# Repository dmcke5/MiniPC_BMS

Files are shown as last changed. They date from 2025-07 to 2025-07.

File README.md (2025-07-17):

# MiniPC BMS
A tiny UPS for powering Mini PC's from battery!

 PMS

## Features:
- USB-C PD charging
- Secondary charger input
- USB-HID UPS communication to provide the operating system with battery information
- Inbuilt fuel gauge IC for accurate battery capacity monitoring
- Extremely low powered-down power consumption (5.1uA)
- Inbuilt 19v boost for stable output at up to 3A.
- Solid state switch for triggering PC power button

## Software:
The software for this project is based on this HID power device library:
https://github.com/abratchik/HIDPowerDevice

The software is complete and functional, although it could use some polish and some comments.
I would recommend changing the "debug" variable in MiniPC_UPS.ino to true before you flash the code for the first time.
This will enable debug output and stop the BMS from trying to shut your computer down due to a "Low battery".
Once you've confirmed all of the values are being read correctly, you should be safe to go back in and set that variable to false
and the BMS will begin functioning.

## Known issues

USB-C PD charging is slow. I found a small issue in the PCB design (which I have now fixed) before uploading that may or may not have solved this problem. I suspect that the issues I've had with this are just down to soldering or faulty hardware because the second charger input works as intended and it is basically identical to the first one after all of the USB PD components. I have checked and the correct values are being requested from the USB charger so the issue has somewhere down the line from the USB PD hardware. This was working for me at one stage, which is why I suspect its an assembly issue.

USB HID is sometimes not detected by windows. This one has been difficult to track down, but I'm certain its a software issue that's causing the problem. A simple restart of the system always seems to rectify the problem so I've left it alone for now.

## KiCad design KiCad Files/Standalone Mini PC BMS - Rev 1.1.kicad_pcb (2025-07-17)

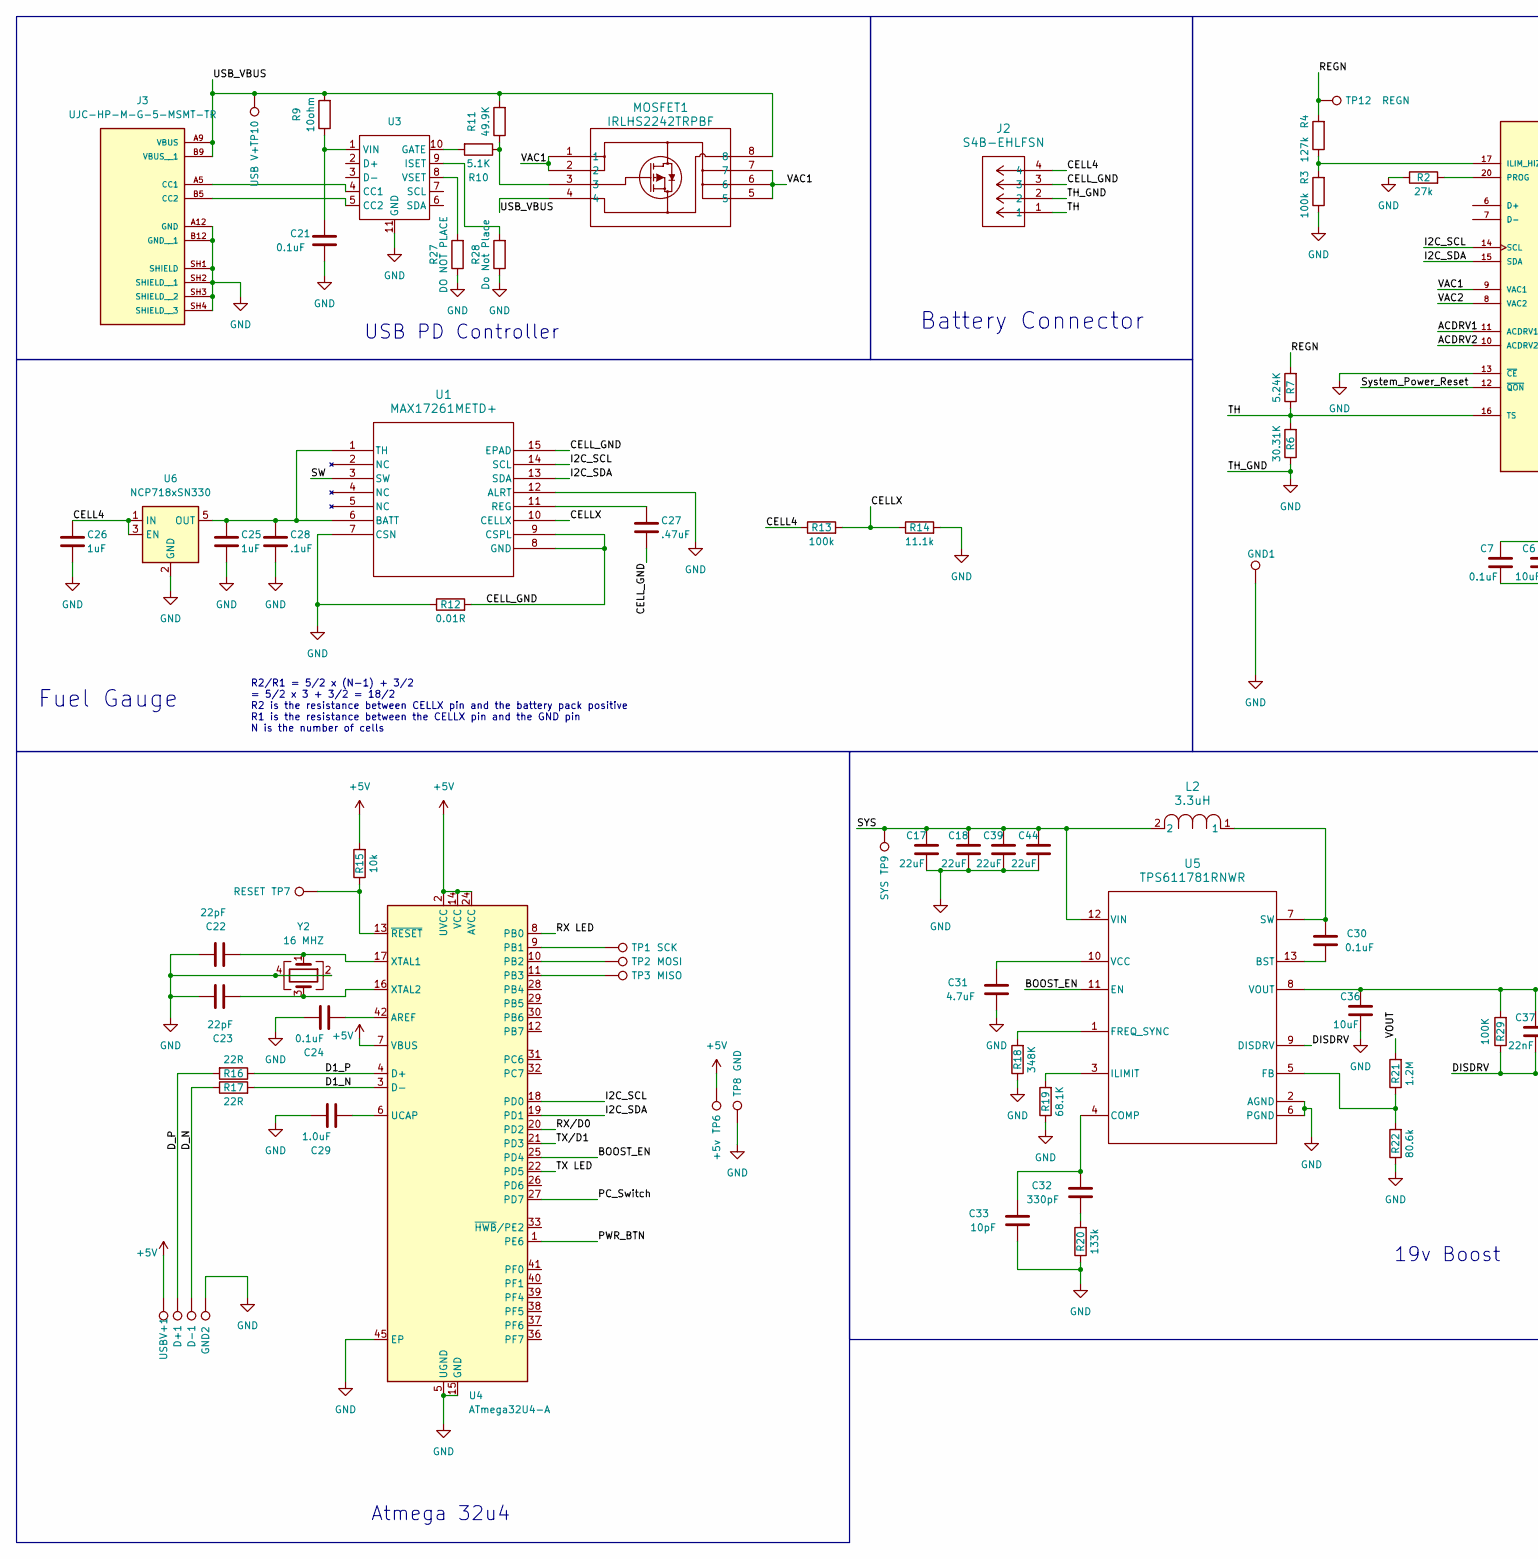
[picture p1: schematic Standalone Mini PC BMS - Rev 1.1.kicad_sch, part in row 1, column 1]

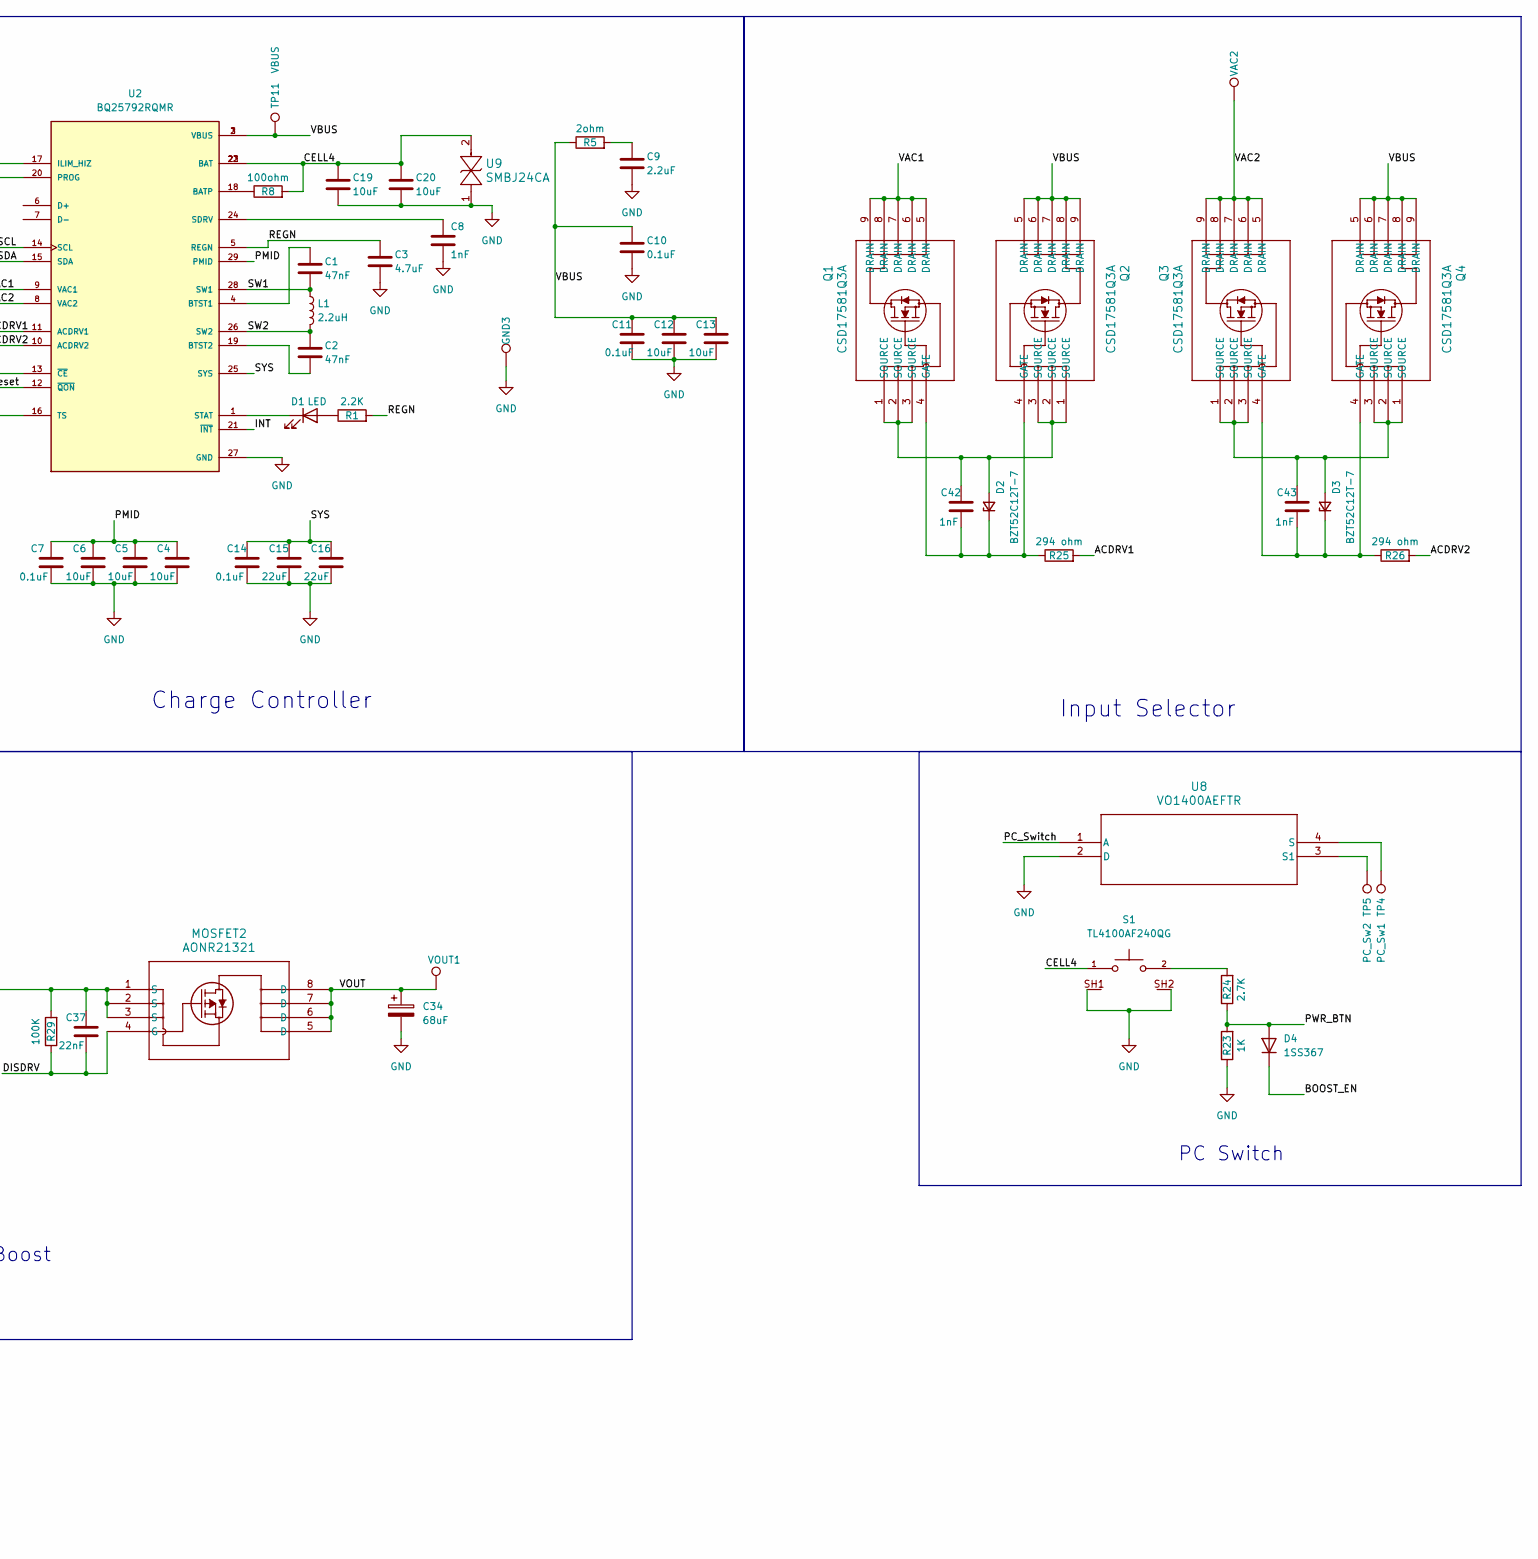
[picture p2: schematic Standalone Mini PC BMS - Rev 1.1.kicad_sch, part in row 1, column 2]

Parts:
C1, C2: 47nF; C_0603_1608Metric
C3, C31: 4.7uF; C_0603_1608Metric
C4, C5, C6, C12, C13, C36: 10uF; C_0805_2012Metric
C7, C10, C11, C14, C24, C30: 0.1uF; C_0603_1608Metric
C8, C42, C43: 1nF; C_0603_1608Metric
C9: 2.2uF; C_0603_1608Metric
C15, C16, C17, C18, C39, C44: 22uF; C_0805_2012Metric
C19, C20: 10uF; C_0603_1608Metric
C21: 0.1uF; C_0603_1608Metric_Pad1.08x0.95mm_HandSolder
C22, C23: 22pF; C_0603_1608Metric
C25, C26: 1uF; C_0603_1608Metric
C27: .47uF; C_0603_1608Metric
C28: .1uF; C_0603_1608Metric
C29: 1.0uF; C_0603_1608Metric
C32: 330pF; C_0603_1608Metric
C33: 10pF; C_0603_1608Metric
C34: 68uF; CP_Radial_D5.0mm_P2.00mm
C37: 22nF; C_0603_1608Metric
D1: LED; LED_0603_1608Metric
D2, D3: BZT52C12T-7; SOD-523_0P9X1P3_ONS
D4: 1SS367; D_SOD-323
D+1: D+; TestPoint_THTPad_D1.5mm_Drill0.7mm
D-1: D-; TestPoint_THTPad_D1.5mm_Drill0.7mm
GND1: GND; TestPoint_THTPad_D2.0mm_Drill1.0mm
GND2, GND3: GND; TestPoint_THTPad_D1.5mm_Drill0.7mm
J2: S4B-EHLFSN; CONN_S4B-EHLFSN_JST
J3: UJC-HP-M-G-5-MSMT-TR; CUI_UJC-HP-M-G-5-MSMT-TR; PARTREV 1.01
L1: 2.2uH; IND_SPM6530_TDK
L2: 3.3uH; IND_1050-WE-HCI_WRE
MOSFET1: IRLHS2242TRPBF; PQFN6_2X2_INF
MOSFET2: AONR21321; DFN8_3x3_EP_AOS
Q1, Q2, Q3, Q4: CSD17581Q3A; Q3A_TEX
R1: 2.2K; R_0603_1608Metric
R2: 27k; R_0603_1608Metric
R3, R13: 100k; R_0603_1608Metric
R4: 127k; R_0603_1608Metric
R5: 2ohm; R_0603_1608Metric
R6: 30.31K; R_0603_1608Metric
R7: 5.24K; R_0603_1608Metric
R8: 100ohm; R_0603_1608Metric
R9: 10ohm; R_0603_1608Metric_Pad0.98x0.95mm_HandSolder
R10: 5.1K; R_0603_1608Metric_Pad0.98x0.95mm_HandSolder
R11: 49.9K; R_0603_1608Metric_Pad0.98x0.95mm_HandSolder
R12: 0.01R; R_2512_6332Metric
R14: 11.1k; R_0603_1608Metric
R15: 10k; R_0603_1608Metric
R16, R17: 22R; R_0603_1608Metric
R18: 348K; R_0603_1608Metric
R19: 68.1K; R_0603_1608Metric
R20: 133k; R_0603_1608Metric
R21: 1.2M; R_0603_1608Metric
R22: 80.6k; R_0603_1608Metric
R23: 1K; R_0603_1608Metric
R24: 2.7K; R_0603_1608Metric
R25, R26: 294 ohm; R_0603_1608Metric
R27: DO NOT PLACE; R_0603_1608Metric_Pad0.98x0.95mm_HandSolder
R28: Do Not Place; R_0603_1608Metric_Pad0.98x0.95mm_HandSolder
R29: 100K; R_0603_1608Metric
S1: TL4100AF240QG; SW_TL4100AF240QG; PARTREV C
TP1: SCK; TestPoint_Pad_D1.0mm
TP2: MOSI; TestPoint_Pad_D1.0mm
TP3: MISO; TestPoint_Pad_D1.0mm
TP4: PC_Sw1; TestPoint_THTPad_D1.5mm_Drill0.7mm
TP5: PC_Sw2; TestPoint_THTPad_D1.5mm_Drill0.7mm
TP6: +5v; TestPoint_Pad_D1.0mm
TP7: RESET; TestPoint_Pad_D1.0mm
TP8: GND; TestPoint_Pad_D1.0mm
TP9: SYS; TestPoint_Pad_D1.0mm
TP10: USB V+; TestPoint_Pad_D1.0mm
TP11: VBUS; TestPoint_Pad_D1.0mm
TP12: REGN; TestPoint_Pad_D1.0mm
U1: MAX17261METD+; 21-0137_T1433+2C_MXM
U2: BQ25792RQMR; QFN40P400X400X100-29N; PARTREV 11/2019
U3: DFN-10-1EP_3x3mm_P0.5mm_EP1.7x2.5mm
U4: ATmega32U4-A; QFN-44-1EP_7x7mm_P0.5mm_EP5.15x5.15mm
U5: TPS611781RNWR; RNW0013A
U6: NCP718xSN330; SOT-23-5
U8: VO1400AEFTR; SO-4_VO_VIS
U9: SMBJ24CA; SMBJ24CA_LTF
USBV+1: USB V+; TestPoint_THTPad_D1.5mm_Drill0.7mm
VAC2: VAC2; TestPoint_THTPad_D1.5mm_Drill0.7mm
VOUT1: V+ OUT; TestPoint_THTPad_D2.0mm_Drill1.0mm
Y2: 16 MHZ; Crystal_SMD_5032-4Pin_5.0x3.2mm

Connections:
+5V: R15.2, TP6.1, U4.2 (UVCC), U4.7 (VBUS), U4.14 (VCC), U4.24 (AVCC), U4.34 (VCC), U4.44 (AVCC), USBV+1.1
/ACDRV1: R25.2, U2.11 (ACDRV1)
/ACDRV2: R26.2, U2.10 (ACDRV2)
/BOOST_EN: D4.1 (K), U4.25 (PD4), U5.11 (EN)
/CELL4: C19.1, C20.1, C26.1, J2.4, R8.2, R13.1, S1.1, U2.22 (BAT), U2.23 (BAT), U6.1 (IN), U6.3 (EN), U9.2
/CELLX: R13.2, R14.1, U1.10 (CELLX)
/CELL_GND: C27.2, J2.3, R12.2, U1.8 (GND), U1.9 (CSPL), U1.15 (EPAD)
/D1_N: R17.2, U4.3 (D-)
/D1_P: R16.1, U4.4 (D+)
/DISDRV: C37.2, MOSFET2.4 (G), R29.1, U5.9 (DISDRV)
/D_N: D-1.1, R17.1
/D_P: D+1.1, R16.2
/I2C_SCL: U1.14 (SCL), U2.14 (SCL), U4.18 (PD0)
/I2C_SDA: U1.13 (SDA), U2.15 (SDA), U4.19 (PD1)
/INT: U2.21 (~INT)
/PC_Switch: U4.27 (PD7), U8.1 (A)
/PMID: C4.1, C5.1, C6.1, C7.1, U2.29 (PMID)
/PWR_BTN: D4.2 (A), R23.2, R24.1, U4.1 (PE6)
/REGN: C3.1, R1.2, R4.2, R7.2, TP12.1, U2.5 (REGN)
/RX LED: U4.8 (PB0)
/RX/D0: U4.20 (PD2)
/SW: U1.3 (SW)
/SW1: C1.2, L1.1, U2.28 (SW1)
/SW2: C2.1, L1.2, U2.26 (SW2)
/SYS: C14.1, C15.1, C16.1, C17.1, C18.1, C39.1, C44.1, L2.2, TP9.1, U2.25 (SYS), U5.12 (VIN)
/System_Power_Reset: U2.12 (~QON)
/TH: J2.1, R6.2, R7.1, U2.16 (TS)
/TX LED: U4.22 (PD5)
/TX/D1: U4.21 (PD3)
/USB_VBUS: J3.A9 (VBUS), J3.B9 (VBUS__1), MOSFET1.4, MOSFET1.8, R9.2, R11.2, TP10.1
/VAC1: MOSFET1.1, MOSFET1.2, MOSFET1.5, MOSFET1.6, MOSFET1.7, Q1.5 (DRAIN), Q1.6 (DRAIN), Q1.7 (DRAIN), Q1.8 (DRAIN), Q1.9 (DRAIN), U2.9 (VAC1)
/VAC2: Q3.5 (DRAIN), Q3.6 (DRAIN), Q3.7 (DRAIN), Q3.8 (DRAIN), Q3.9 (DRAIN), U2.8 (VAC2), VAC2.1
/VBUS: C10.1, C11.1, C12.1, C13.1, Q2.5 (DRAIN), Q2.6 (DRAIN), Q2.7 (DRAIN), Q2.8 (DRAIN), Q2.9 (DRAIN), Q4.5 (DRAIN), Q4.6 (DRAIN), Q4.7 (DRAIN), Q4.8 (DRAIN), Q4.9 (DRAIN), R5.1, TP11.1, U2.2 (VBUS), U2.3 (VBUS)
/VOUT: C34.1, MOSFET2.5 (D), MOSFET2.6 (D), MOSFET2.7 (D), MOSFET2.8 (D), R21.2, VOUT1.1
GND: C3.2, C4.2, C5.2, C6.2, C7.2, C8.2, C9.2, C10.2, C11.2, C12.2, C13.2, C14.2, C15.2, C16.2, C17.2, C18.2, C19.2, C20.2, C21.2, C22.1, C23.1, C24.1, C25.2, C26.2, C28.2, C29.1, C31.1, C33.1, C34.2, C36.2, C39.2, C44.2, GND1.1, GND2.1, GND3.1, J2.2, J3.A12 (GND), J3.B12 (GND__1), J3.SH1 (SHIELD), J3.SH2 (SHIELD__1), J3.SH3 (SHIELD__2), J3.SH4 (SHIELD__3), R2.1, R3.1, R6.1, R12.1, R14.2, R18.1, R19.1, R20.1, R22.1, R23.1, R27.1, R28.1, S1.SH1, S1.SH2, TP8.1, U1.7 (CSN), U1.12 (ALRT), U2.13 (~CE), U2.27 (GND), U3.11 (GND), U4.5 (UGND), U4.15 (GND), U4.23 (GND), U4.35 (GND), U4.43 (GND), U4.45 (EP), U5.2 (AGND), U5.6 (PGND), U6.2 (GND), U8.2 (D), U9.1, Y2.2, Y2.4
unnamed: C9.1, R5.2
unnamed: C32.1, R20.2
unnamed: D1.2 (A), R1.1
unnamed: D1.1 (K), U2.1 (STAT)
unnamed: C42.1, D2.2 (A), Q1.1 (SOURCE), Q1.2 (SOURCE), Q1.3 (SOURCE), Q2.1 (SOURCE), Q2.2 (SOURCE), Q2.3 (SOURCE)
unnamed: C42.2, D2.1 (K), Q1.4 (GATE), Q2.4 (GATE), R25.1
unnamed: C43.1, D3.2 (A), Q3.1 (SOURCE), Q3.2 (SOURCE), Q3.3 (SOURCE), Q4.1 (SOURCE), Q4.2 (SOURCE), Q4.3 (SOURCE)
unnamed: C43.2, D3.1 (K), Q3.4 (GATE), Q4.4 (GATE), R26.1
unnamed: J3.A5 (CC1), U3.4 (CC1)
unnamed: J3.B5 (CC2), U3.5 (CC2)
unnamed: MOSFET1.3, R10.1, R11.1
unnamed: R24.2, S1.2
unnamed: C25.1, C28.1, U1.1 (TH), U1.6 (BATT), U6.5 (OUT)
unnamed: C27.1, U1.11 (REG)
unnamed: R8.1, U2.18 (BATP)
unnamed: C1.1, U2.4 (BTST1)
unnamed: C2.2, U2.19 (BTST2)
unnamed: R3.2, R4.1, U2.17 (ILIM_HIZ)
unnamed: R2.2, U2.20 (PROG)
unnamed: C8.1, U2.24 (SDRV)
unnamed: R10.2, U3.10 (GATE)
unnamed: R28.2, U3.9 (ISET)
unnamed: C21.1, R9.1, U3.1 (VIN)
unnamed: R27.2, U3.8 (VSET)
unnamed: C24.2, U4.42 (AREF)
unnamed: TP1.1, U4.9 (PB1)
unnamed: TP2.1, U4.10 (PB2)
unnamed: TP3.1, U4.11 (PB3)
unnamed: C29.2, U4.6 (UCAP)
unnamed: C22.2, U4.17 (XTAL1), Y2.1
unnamed: C23.2, U4.16 (XTAL2), Y2.3
unnamed: R15.1, TP7.1, U4.13 (~RESET)
unnamed: C30.1, U5.13 (BST)
unnamed: C32.2, C33.2, U5.4 (COMP)
unnamed: R21.1, R22.2, U5.5 (FB)
unnamed: R18.2, U5.1 (FREQ_SYNC)
unnamed: R19.2, U5.3 (ILIMIT)
unnamed: C30.2, L2.1, U5.7 (SW)
unnamed: C31.2, U5.10 (VCC)
unnamed: C36.1, C37.1, MOSFET2.1 (S), MOSFET2.2 (S), MOSFET2.3 (S), R29.2, U5.8 (VOUT)
unnamed: TP5.1, U8.3 (S1)
unnamed: TP4.1, U8.4 (S)

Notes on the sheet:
USB PD Controller
19v Boost
Atmega 32u4
PC Switch
Input Selector
Fuel Gauge
R2/R1 = 5/2 x (N-1) + 3/2 = 5/2 x 3 + 3/2 = 18/2 R2 is the resistance between CELLX pin and the battery pack positive R1 is the resistance between the CELLX pin and the GND pin N is the number of cells
Battery Connector
Charge Controller

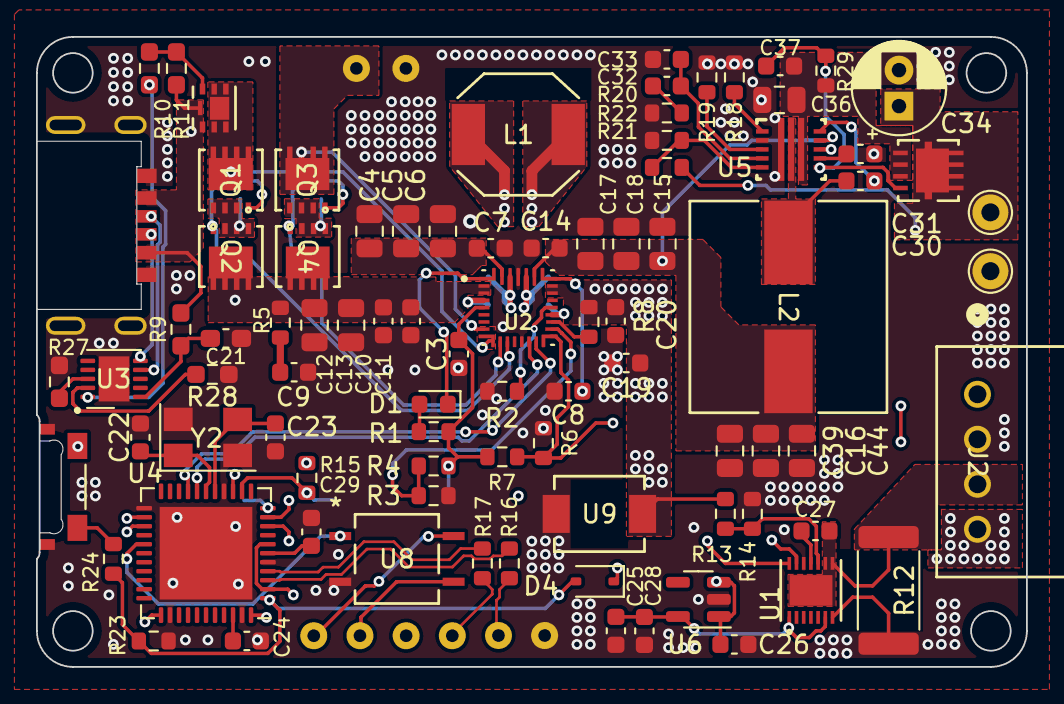
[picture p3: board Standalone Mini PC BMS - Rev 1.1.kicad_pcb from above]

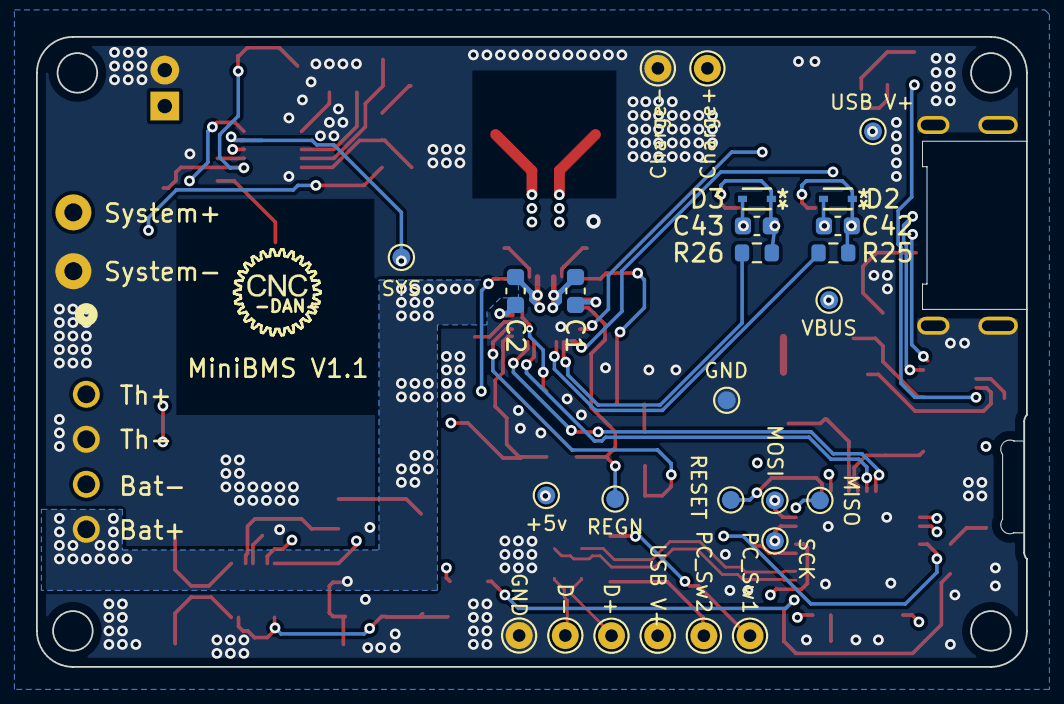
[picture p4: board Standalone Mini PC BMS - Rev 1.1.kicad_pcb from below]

Board: 4 copper layers, 55.0 x 35.0 mm, 113 parts (26 on the bottom side), 70 nets.

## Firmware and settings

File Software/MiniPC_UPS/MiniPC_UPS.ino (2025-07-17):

#include <Wire.h>
#include <HIDPowerDevice.h>
//#include <LowPower.h>

//User Config
#define powerOffDelay 10000 //Time in milliseconds to hold power button for hard shut off
#define shutdownDelay 2000  //Time in milliseconds to hold power button to initiate Shutdown
#define reportDelay 5000    //Time in milliseconds. How often to Update UPS info
int batteryCapacity = 5000; //Battery Design Capacity in mAh
bool disableAutoShutoff = false; //Used to disable power sense shutdown for testing
bool debug = false;         //Set to True to disable UPS functionality and enable serial logging.
bool forceFuelGaugeReset = false; //Set to True to reset fuel gauge on startup. Learnt battery information will be lost!

//Pin configuration
int boostEnable = 4; //PD4 // Enables 19v Boost Output
int pcSwitch = 6; //PD7  // High to trigger PC power button press
//int pcPower = 12; //PD6 // Input to sense if PC is powered on
int pwrButton = 7; //PE6 // Power button

//bool systemAwake = true;
int StatusPOR = 0; //This Variable is set to 1 by the Fuel gauge on first power up
bool updateBQ = false;

//Timers
unsigned long shutdownTimer = 0;
unsigned long powerBtnTimer = 0;
unsigned long reportTimer = 0;

//UPS
int batterySOC;
bool bCharging = false;
bool bACPresent = false;
bool bDischarging = false;
byte iRemaining =0, iPrevRemaining=0;
bool lastACState = false;
bool lastChargeState = false;

int powerSupplyState = 0; //0 = Active, 1 = Sleep, 2 = Powered Down

void setup() {
  TXLED0;
  RXLED0;
  if(debug){
    Serial.begin(57600);
    while(!Serial){}
  }
  Wire.begin();

  max17261Init(); //Set up fuel gauge

  //Configure IO pins
  pinMode(boostEnable, OUTPUT);
  pinMode(pcSwitch, OUTPUT);
  //pinMode(pcPower, INPUT);
  pinMode(pwrButton, INPUT);

  //Enable Boost 
  digitalWrite(boostEnable, HIGH);

  //Setup UPS
  if(!debug){
    UPS_Setup();
  }

  //Setup BQ25792
  if(updateBQ){
    bqConfig();
  }
  //digitalWrite(pcSwitch, HIGH);
  //readAllRegisters();
}

void loop() {
  if(digitalRead(pwrButton) == 1){ //Power button pressed
    if(powerBtnTimer == 0){ //If power button timer isn't started
      powerBtnTimer = millis(); //Start timer
      if(debug){
        Serial.println("Button Pressed");
      }
    }
    if(powerBtnTimer + powerOffDelay < millis()){ //If ten seconds has elapsed
      shutDownPSU(); // Trigger shutdown sequence
    }
  } else { //power button released
    if(powerBtnTimer != 0){ //power button timer is set
      if(powerBtnTimer + shutdownDelay < millis()){ //power button was held for more than shutdownDelay
        //Initiate PC Shutdown
        if(debug){
          Serial.println("Shutdown PC");
        }
        shutdownPC();
      } else { //power button wasn't held for more than one second
        if(debug){
          Serial.println("Sleep PC");
        }
        sleepPC(); //Initiate PC Sleep
      }
      powerBtnTimer = 0; //Reset power button timer
    }
  }
  
  /*if(shutdownTimer != 0 && shutdownTimer + 3000 < millis()){ //Shutdown timer is active and expired
    shutDownPSU();
  }*/
  iRemaining = getSOC();
  int temp = GetChargeStatus();
  if(temp != 0 && temp != 7){ //0 = Not Charging, 7 = Charge Termination Done
    bCharging = true;
  } else {
    bCharging = false;
  }
  if(GetACDRV1Status() || GetACDRV2Status()){
    bACPresent = true;
  } else {
    bACPresent = false;
  }

  //Force instant UPS report when charger disconnected/connected
  if(lastACState != bACPresent){
    lastACState = bACPresent;
    reportTimer = 0;
  }
  if(lastChargeState != bCharging){
    lastChargeState = bCharging;
    reportTimer = 0;
  }

  if(reportTimer + reportDelay < millis()){
    if(debug){
      Serial.print("SOC = ");
      Serial.println(getSOC());
      Serial.print("Remaining Capacity = ");
      Serial.println(getRemainingCapacity());
      Serial.print("Pack Voltage = ");
      Serial.println(getInstantaneousVoltage() * 4);
      Serial.print("V Empty = ");
      Serial.println(getVEmpty());
      Serial.print("Pack Capacity = ");
      Serial.println(getCapacity());
      Serial.print("Calculated Pack Capacity = ");
      Serial.println(getRealCapacity());
      Serial.print("iRemaining = ");
      Serial.println(iRemaining);
      Serial.print("Current = ");
      Serial.println(getInstantaneousCurrent());
      Serial.print("Charging = ");
      Serial.println(bCharging);
      Serial.print("AC Present = ");
      Serial.println(bACPresent);

      readAllFaultRegisters();
      if(bCharging){
        Serial.print("TTF = ");
        Serial.println(getTimeToFull() * 60);
      } else {
        Serial.print("TTE = ");
        Serial.println(getTimeToEmpty() * 60);
      }
      
      Serial.println();
    } else {
      UPS_Report();
    }
    reportTimer = millis();
  }
}

void sleepPC(){
  digitalWrite(pcSwitch, HIGH);
  delay(100);
  digitalWrite(pcSwitch, LOW);
}

void shutdownPC(){
  digitalWrite(pcSwitch, HIGH);
  delay(2000);
  digitalWrite(pcSwitch, LOW);
}

void shutDownPSU(){
  digitalWrite(boostEnable, LOW); //Disable Boost Converter
}

void bqConfig(){ //Call to configure BQ register settings after shutdown
  SetWatchdogTimerSetting(0);
  SetInputCurrentLimit(3000); //Set input current to maximum
  SetEN_EXTILIM(false);
  SetChargeCurrentLimit(3000); //Set charge current to 3A
}

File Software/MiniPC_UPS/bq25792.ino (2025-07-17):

#define bq25792Addr 0x6B

#define DevicePartNumberMask 0b00111000
#define PrechargeCurrentLimitMask 0b00111111
#define ChargerStatus0PowerGoodStatusMask 0b00001000
#define ChargerStatus1ChargeStatusMask 0b11100000
#define ChargerStatus1VbusStatusMask 0b00011110
#define ChargerStatus1Bc12DetectionMask 0b00000001
#define ChargerControl1WatchdogMask 0b00000111
#define AdcControlEnableMask 0b10000000
#define AdcControlConversionRateMask 0b01000000
#define AdcControlResolutionMask 0b00110000
#define AdcControlAverageControlMask 0b00001000
#define AdcControlInitialAverageMask 0b00000100
#define ThermalRegulationThresholdMask 0b00000011
#define ThermalShutdownThresholdMask 0b00001100
#define ChargerStatus3IcoStatusMask 0b11000000
#define NtcControl0ChargerVoltageMask 0b11100000
#define NtcControl0ChargeCurrentMask 0b00011000
#define NtcControl1Vt2ComparatorVoltageMask 0b11000000
#define NtcControl1Vt3ComparatorVoltageMask 0b00110000
#define NtcControl1OtgHotTemperatureMask 0b00001100
#define NtcControl1OtgColdTemperatureMask 0b00000010
#define NtcControl1IgnoreTSMask 0b00000001
#define EN_ACDRV1Mask 0b01000000
#define EN_ACDRV2Mask 0b10000000
#define ChargeENMask 0b00100000
#define EN_EXTILIMMask 0b00000010

int FixedOffsetMinimalSystemVoltage = 2500;
int MaxValueMinimalSystemVoltage = 16000;
int StepMinimalSystemVoltage = 250;
int PrechargeCurrentLimitMinValue = 40;
int StepPrechargeCurrentLimit = 40;
int PrechargeCurrentLimitMaxValue = 2000;
int FixedOffsetMinimalChargeVoltageLimit = 3000;
int MaxValueChargeVoltageLimit = 18800;
int FixedOffsetMinimalChargeCurrentLimit = 50;
int MaxValueChargeCurrentLimit = 5000;
int MaxValueInputVoltageLimit = 22000;
int MinValueInputVoltageLimit = 3600;
int FixedOffsetMinimalInputCurrentLimit = 100;
int MaxValueInputCurrentLimit = 3300;

int VbusAdcStep = 1;
int ChargeVoltageStep = 10;
int ChargeInputCurrentStep = 10;
int InputVoltageStep = 100;
float TdieStemp = 0.5f;

#define REG00_Minimal_System_Voltage 0x01
#define REG01_Charge_Voltage_Limit 0x01
#define REG03_Charge_Current_Limit 0x03
#define REG05_Input_Voltage_Limit 0x05
#define REG06_Input_Current_Limit 0x06
#define REG08_Precharge_Control 0x08
#define REG0F_Charger_Control_0 0x0F
#define REG10_Charger_Control_1 0x10
#define REG13_Charger_Control_4 0x13
#define REG14_Charger_Control_5 0x14
#define REG16_Temperature_Control 0x16
#define REG17_NTC_Control_0 0x17
#define REG18_NTC_Control_1 0x18

#define REG1B_Charger_Status_0 0x1B
#define REG1C_Charger_Status_1 0x1C
#define REG1D_Charger_Status_2 0x1D
#define REG1E_Charger_Status_3 0x1E
#define REG1F_Charger_Status_4 0x1F
#define REG20_FAULT_Status_0 0x20
#define REG21_FAULT_Status_1 0x21
#define REG22_Charger_Flag_0 0x22
#define REG23_Charger_Flag_1 0x23
#define REG24_Charger_Flag_2 0x24
#define REG25_Charger_Flag_3 0x25
#define REG26_FAULT_Flag_0 0x26
#define REG27_FAULT_Flag_1 0x27

#define REG2E_ADC_Control 0x2E
#define REG35_VBUS_ADC 0x35
#define REG37_VAC1_ADC 0x37
#define REG39_VAC2_ADC 0x39
#define REG3B_VBAT_ADC 0x3B
#define REG3D_VSYS_ADC 0x3D
#define REG41_TDIE_ADC 0x41
#define REG48_Part_Information 0x48
#define REG0E_Timer_Control 0x0E

byte buffer[10];

void ReadFromRegister(int addr, int reg, int readByteCount) {
  Wire.beginTransmission(addr);
  Wire.write(reg);
  Wire.endTransmission();
  Wire.requestFrom(bq25792Addr,readByteCount,true);
  int count = 0;
  while (Wire.available()) {
    buffer[count] = Wire.read();
    count++;
  }
}

void WriteToRegister(int addr, int reg, int length) { //Writes specified number of bytes from Global buffer to register
  Wire.beginTransmission(addr);
  Wire.write(reg);
  for(int i = 0; i < length; i++){
    Wire.write(buffer[i]);
  }
  /*for(int i = length - 1; i > 0; i--){
    Wire.write(buffer[i]);
  }*/
  Wire.endTransmission();
}

void ResetWatchdog() {
  buffer[0] = 0x08;
  WriteToRegister(bq25792Addr, REG10_Charger_Control_1, 1);//0b00001000);//8);
  //WriteToRegister(bq25792Addr, bq25792Addr, Register.REG10_Charger_Control_1, 0b0000_1000);
}

void SetChargeEnabled() {
  buffer[0] = 0b00010000;
  WriteToRegister(bq25792Addr, REG0E_Timer_Control, 1);//0b00001000);//8);
  //WriteToRegister(bq25792Addr, bq25792Addr, Register.REG10_Charger_Control_1, 0b0000_1000);
}

int GetChargerStatus0() {
  ReadFromRegister(bq25792Addr, REG1C_Charger_Status_1, 1);
  return buffer[0];
}

void readAllFaultRegisters(){
  for(int i = 27; i < 39; i++){
    Serial.print("Register ");
    Serial.print(i);
    Serial.print(" = ");
    ReadFromRegister(bq25792Addr, i, 1);
    Serial.println(buffer[0]);
  }
}

void readAllRegisters(){
  for(int i = 0; i < 73; i++){
    if(i != 0x02 && i != 0x04 && i != 0x07 && i != 0x0C && i != 0x1A && i != 0x32 && i != 0x34 && i != 0x36 && i != 0x38 && i != 0x3A && i != 0x3C && i != 0x3E && i != 0x42 && i != 0x44 && i != 0x46){
      Serial.print("Register ");
      Serial.print("0x");
      Serial.print(i < 16 ? "0" : "");
      Serial.print(i, HEX);
      
      if(i == 0x01 || i == 0x03 || i == 0x06 || i == 0x0B || i == 0x19 || i == 0x31 || i == 0x33 || i == 0x35 || i == 0x37 || i == 0x39 || i == 0x3B || i == 0x3D || i == 0x3F || i == 0x41 || i == 0x43 || i == 0x45){
        ReadFromRegister(bq25792Addr, i, 2);
        int output = (buffer[0] << 8) | buffer[1];
        Serial.print(" = ");
        Serial.print("0x");
        Serial.print(output < 16 ? "0" : "");
        Serial.println(output, HEX);
      } else {
        Serial.print(" = ");
        ReadFromRegister(bq25792Addr, i, 1);
        Serial.print("0x");
        Serial.print(buffer[0] < 16 ? "0" : "");
        Serial.println(buffer[0], HEX);
      }
    }
  }
}

int GetFaultStatus0() {
  ReadFromRegister(bq25792Addr, REG20_FAULT_Status_0, 1);
  return buffer[0];
}

int GetFaultFlag0() {
  ReadFromRegister(bq25792Addr, REG26_FAULT_Flag_0, 1);
  return buffer[0];
}
int GetFaultFlag1() {
  ReadFromRegister(bq25792Addr, REG27_FAULT_Flag_1, 1);
  return buffer[0];
}

int GetFaultStatus1() {
  ReadFromRegister(bq25792Addr, REG21_FAULT_Status_1, 1);
  return buffer[0];
}

int GetChargerStatus3() {
  ReadFromRegister(bq25792Addr, REG1E_Charger_Status_3, 2);
  return (buffer[1] << 8) | buffer[0];
}

int GetChargeControl4() {
  ReadFromRegister(bq25792Addr, REG13_Charger_Control_4, 1);

  return buffer[0];
}

bool GetACDRV1Status(){
  ReadFromRegister(bq25792Addr, REG13_Charger_Control_4, 1);
  return (buffer[0] & EN_ACDRV1Mask) != 0;
}

bool GetACDRV2Status(){
  ReadFromRegister(bq25792Addr, REG13_Charger_Control_4, 1);
  return (buffer[0] & EN_ACDRV2Mask) != 0;
}

int GetChargeStatus() {
  ReadFromRegister(bq25792Addr, REG1C_Charger_Status_1, 1);

  return buffer[0];// & ChargerStatus1ChargeStatusMask;
}

int GetVbusStatus() {
  ReadFromRegister(bq25792Addr, REG1C_Charger_Status_1, 1);

  return buffer[0] & ChargerStatus1VbusStatusMask;
}

bool GetBc12Detection() {
  ReadFromRegister(bq25792Addr, REG1C_Charger_Status_1, 1);

  return (buffer[0] & ChargerStatus1Bc12DetectionMask) == 1;
}
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

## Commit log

2025-07-02 Added Project Files
    [Standalone Mini PC BMS - Rev 1.1.kicad_pcb, Standalone Mini PC BMS - Rev 1.1.kicad_sch]
2025-07-17 Fixed filled zone on net D2-A
    [Standalone Mini PC BMS - Rev 1.1.kicad_pcb]
2025-07-17 Added software and known issues to readme
    [MiniPC_UPS.ino, USB_UPS.ino, bq25792.ino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]
